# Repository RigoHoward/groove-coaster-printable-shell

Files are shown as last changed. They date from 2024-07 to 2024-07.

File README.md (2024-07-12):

<h1 align="center">Groove-Coaster Printable-Shell by Rigo Howard</h1>
<h3 align="center">A nice 3D printable frame/shell for a DIY Groove Coaster controller</h3>

<h3 align="left">Overview:</h3>
<p align="left">
Here you will find the needed 3D print files and directions to build a nice looking Groove Coaster shell and get your own DIY-ASC controller!</p>
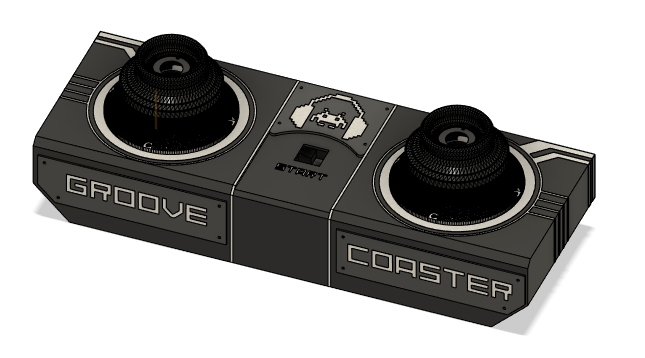
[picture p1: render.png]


<h3 align="left">Finished Controller Sample:</h3>
<p align="left">
Some glamour shots</p>
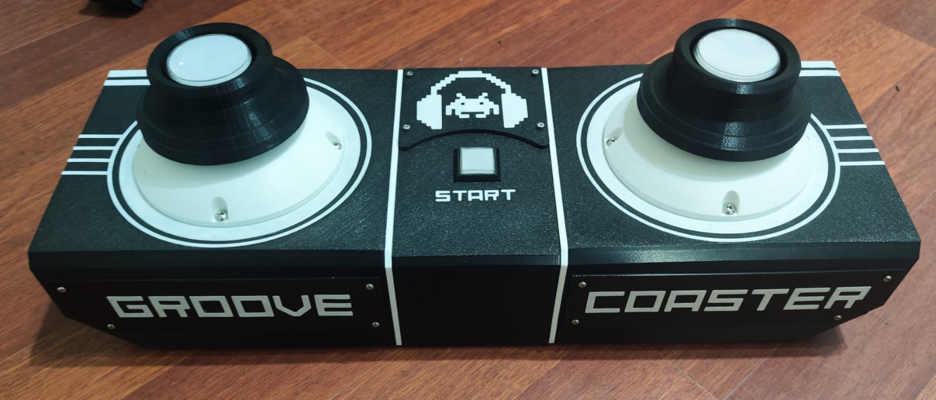
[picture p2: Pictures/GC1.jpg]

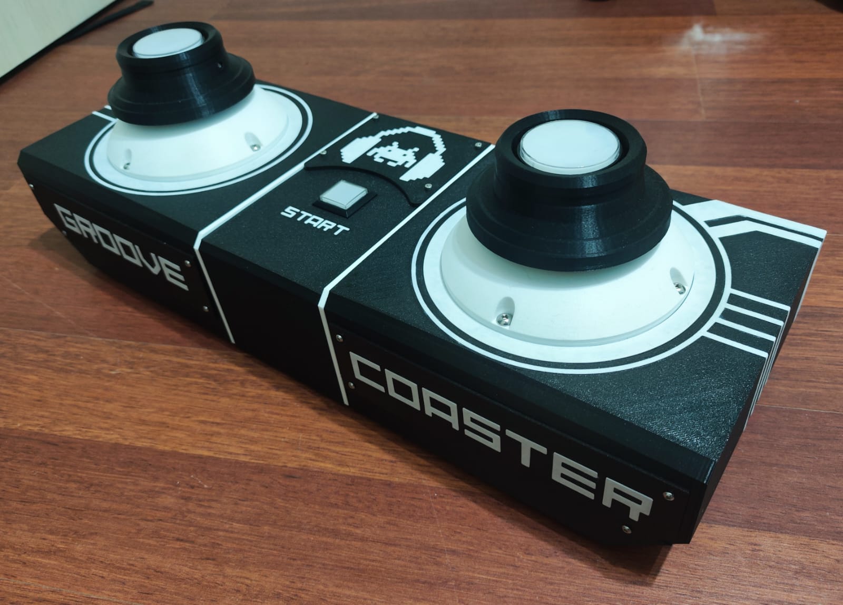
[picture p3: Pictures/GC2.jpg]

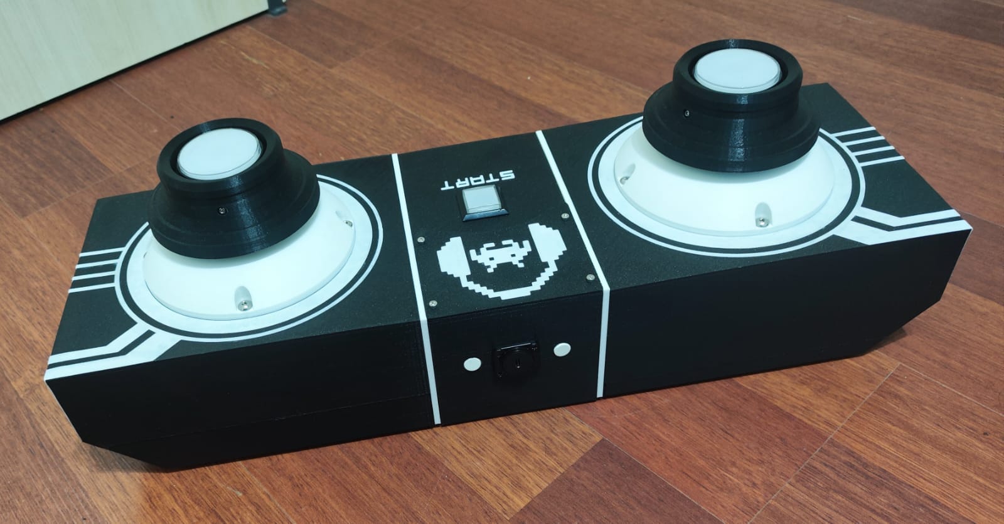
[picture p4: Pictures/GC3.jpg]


<h3 align="left">Extra parts/tools needed:</h3>
<p align="left">
Apart from the 3D printed parts you will need the following tools and materials (there are some Aliexpress links as reference):
  <ul>
  <li>1x Arduino Leonardo or clone board.</li>
  <li><a href="https://www.aliexpress.com/item/1005006560397920.html?spm=a2g0o.cart.0.0.67ac38daT6iGZ6&mp=1">2x Arcade sticks (Sanwa JLF like clones are good, there are 5 pin header and microswitch versions)</a></li>
  <li><a href="https://www.aliexpress.com/item/4000959586079.html?spm=a2g0o.cart.0.0.67ac38daT6iGZ6&mp=1">2x Round 60mm white pushbuttons.</a></li>
  <li><a href="https://www.aliexpress.com/item/33057798976.html?spm=a2g0o.cart.0.0.67ac38daT6iGZ6&mp=1">1x 33x33mm square white pushbutton.</a></li>
  <li>Some female quick disconnects to easily connect/disconnect wires to the sticks and pushbuttons.</li>
  <li><a href="https://www.aliexpress.com/item/1005002669156285.html?spm=a2g0o.cart.0.0.46e638da38WDFw&mp=1">2x Small round white momentary pushbuttons.</a></li>
  <li><a href="https://www.aliexpress.com/item/1005003082350902.html?spm=a2g0o.cart.0.0.67ac38daT6iGZ6&mp=1">2x Soft microswitches for the Left and Right pushbuttons.</a></li>    
  <li><a href="https://www.aliexpress.com/item/1005003307588072.html?spm=a2g0o.cart.0.0.389a38daMdQKNv&mp=1">1x Neutrik like female USB C to Female USB A panel connector.</a></li>
  <li>A few M5 bolts and nuts.</li>
  <li>A few M3 bolts.</li>  
  <li>Some M3 heat inserts.</li>
  <li>4x Rubber feet.</li>
  <li>1 meter of WS2812 ledstrip.</li>
  <li>1x short USB micro to USB-A wire to connect Arduino Leonardo to the USB-C panel connector.</li>
  <li>Solder, Flux and Soldering Iron (and basic soldering skills)</li>
  <li>Some wire cutter and a crimping tool for the quick disconnects.</li>      
  <li>Some shrink tube for cable joints.</li>  
  <li>About 3 meters of 24awg cable.</li>
  <li>Male dupont cables.</li>  
  <li>2x 5mm leds (colors of your preference)</li>  
  </ul>
</p>

<h3 align="left">Parts to print:</h3>
<p align="left">
  <ul>
  <li>1x Left, Center and Right frame.</li>
  <li>1x Bottom Left, Center and Right plate (you could use an accent color for this)</li>
  <li>2x Frame Spacer (you should use an accent color for this)</li>
  <li>1x Left, Right, Logo and Front plates.</li>  
  <li>1x each file on INSERTS folder (you should use an accent color for this)</li>
  <li>2x Joy Base, Joy Tube, Joy Button and Stick Spacer parts.</li>
  </ul>
</p>

<h3 align="left">Printing settings:</h3>
<p align="left">I used the following parameters on my slicer profile:
 <ul>
   <li>Layer Height 0.2 (i use a 0.4mm nozzle)</li>
   <li>3 or 4 walls/perimeters.</li>
   <li>15-20% infill is enough.</li>
   <li>Enabled normal supports on build plate only for Joy Tube and Joy Button parts.</li>
   <li>You really should use a brim or mouse ear brim for the Frame Parts (because they are big and take a long time to print)</li>
 </ul>  
</p>

<h3 align="left">Printing orientation:</h3>
<p align="left">All the Plate parts having some logo/letters engraved on them, must face up its engraving marks.
  For the rest, Please check the <a href="https://github.com/RigoHoward/groove-coaster-printable-shell/tree/main/Print_Orientation">Print_Orientarion</a> folder for pictured details.
</p>

<h3 align="left">Assembly:</h3>
<p align="left">
    <ul>
    <li>Attach the Insert parts to the Left, Center, Right Frame, the Logo Plate, Front Left and Right plates using some CA glue or whatever you use to glue your 3D printed parts.</li>      
    <li>Attach the USB-C panel to the back of the Center Frame and attach it using some M3 screws nuts and bolts. Also screw in the two small round white momentary pushbuttons and fix them with its own washer and nuts.</li>   
    <li>Using 4 M5 screws, washer and nuts put together the Left, Center and Right Frame parts using the 3D printed Frame Spacers between them to build the body of the controller.</li> 
    <li>Put 4 heated M3 inserts on the tiny holes on the top of the Center Frame to screw in the Logo plate later.</li>     
    <li>Using 4 M3 screws attach the Logo plate on top of the center Frame. Also with some M3 screws, washers and nuts fix the Front Left and Right Plate to the front of the Left and Right Frame parts.</li>      
    <li>Attach every JLF like joystick to the Stick Spacer part using two M5 screws on each Spacer.</li>    
    <li>Solder the corrresponding 3 wires (DIN, GND and VIN) to each piece of the ledstrip, then remove the back layer of the ledstrip to expose the sticky surface, and then pass the cables trough the hole in the inner wall of the Joy Base part and slide your ledstrip to glue it in place (leds should be facing outwards) repeat for the other Joy Base part.</li> 
    <li>Assemble the printed Joy Tube parts on the JLF like arcade sticks shafts using two M4 button head screws (do not overtight the screws)</li>  
    <li>Using 4 M5 screws, washer and nuts put together the Joy Base over the Left and Right Frame parts using the corresponding guide holes.</li>
    <li>Change the default microswitch on the 60mm buttons if you got the lighter ones before the next step.</li>      
    <li>Assemble the 60mm buttons on the Joy Button part, and solder the wires to the microswitch and leds.</li>
    <li>Assemble the Joy Button and the Joy Tube parts together routing the cables and twisting the recessed part into its lock position and then add a M3 screw to avoid unlocking.</li>
    <li>Solder each wire to the microswitchs or th 5 pin header (depending on what version you got) on each JLF like joystick.</li>
    <li>Solder the Center frame back momentary pushbuttons and the PLUS button LED to the corresponding pins in the Arduino Board (check the pinout section below)</li>
    <li>Put the heated M3 inserts on all the holes for the supporting Plate tabs for every Frame part at the bottom.</li>      
    <li>Assemble the Bottom Plates of each part of the frame using M3 screws and for each of the outer most sides use some rubber feet, confirm everything works before tightening up.</li>
  </ul>

</p>

<h3 align="left">Soldering:</h3>
<p align="left">
  <ul>
    <li>Solder a daisy chained GND wire to all leds, joysticks, buttons and ledstrips.</li>
    <li>Solder pins 4, 5, 6, 7, 8, 9, 10 and 11 to the left and right joysticks.</li>
    <li>Solder pins 0 and 1 to Left and Right buttons.</li>
    <li>Solder pins A0, A1 and 13 to the Minus, Home and Plus buttons.</li>
    <li>Solder pins 2, 3 and 12 to the Left, Right and Plus led buttons.</li>
    <li>Solder a daisy chained VCC wire to the VIN point on each piece of the ledstrip.</li>
    <li>Solder pins A2 and A3 to the DIN point on the Left and Right ledstrip piece.</li>
  </ul>
</p>

<h3 align="left">Flashing the Code:</h3>
<p align="left">
Follow the building instructions for the awesome <a href="https://github.com/CrazyRedMachine/LUFAHybridFightstick?tab=readme-ov-file#building-instructions">LUFAHybridFightstick</a> repository made by <b>CrazyRedMachine</b> until the fifth step and then flash the code i leave <a href="https://github.com/RigoHoward/groove-coaster-printable-shell/tree/main/Software/GC_RH">HERE</a> (which its actually his code with a different pinout and a rainbow animation effect for the ledstrip only)
</p>

<h3 align="left">Current Pinout:</h3>
<p align="left">
Here it is the pinout i used for each stick, button, led and ledstrip.
</p>

```
/* PINOUT (follows Nintendo naming (X=up, B=down)) */
#define PIN_UP    4
#define PIN_DOWN  5
#define PIN_LEFT  6
#define PIN_RIGHT 7
#define PIN_A     11          //XBOX B
#define PIN_B     9           //XBOX A  
#define PIN_X     8           //XBOX Y
#define PIN_Y     10          //XBOX X     
#define PIN_L     0           //XBOX LB
#define PIN_R     1           //XBOX RB
#define PIN_PLUS  13          //XBOX START
#define PIN_MINUS A0          //XBOX BACK
#define PIN_HOME  A1
#define PIN_L_LED  2
#define PIN_R_LED  3
#define PIN_PLUS_LED 12
#define DATA_PIN1 A2         //ledstrip Left
#define DATA_PIN2 A3         //ledstrip Right
```

<h3 align="left">Thanks to:</h3>
<p align="left">All the work done here was possible with the help of these awesome fellows:
<ul>
  <li><a href="https://github.com/CrazyRedMachine">CrazyRedMachine</a>: for the LufaHybridStick code and constant help on coding.</li>
  <li><a href="https://github.com/paatchii">Patchii</a>: for the initial STL files i used as reference to work on my remixed parts.</li>
  <li>Thomas (from C&S discord): for his modular 3D cases for rythm controllers inspiration.</li>
  <li>All the Cons & Stuff discord community for being so cool and nice.</li>
</ul>
</p>

<h3 align="left">Do you think i do cool stuff?, what about a nice cup of coffee for me?!:</h3>
<p><a href="https://www.buymeacoffee.com/rigohoward"> rigohoward</a></p><br><br>

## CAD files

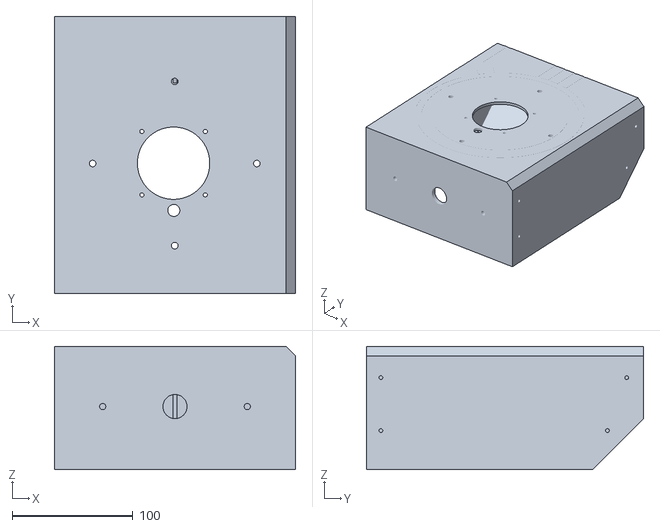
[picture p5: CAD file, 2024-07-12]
STLS/FRAME/Right_Frame.stl
200.0 x 230.0 x 102.4

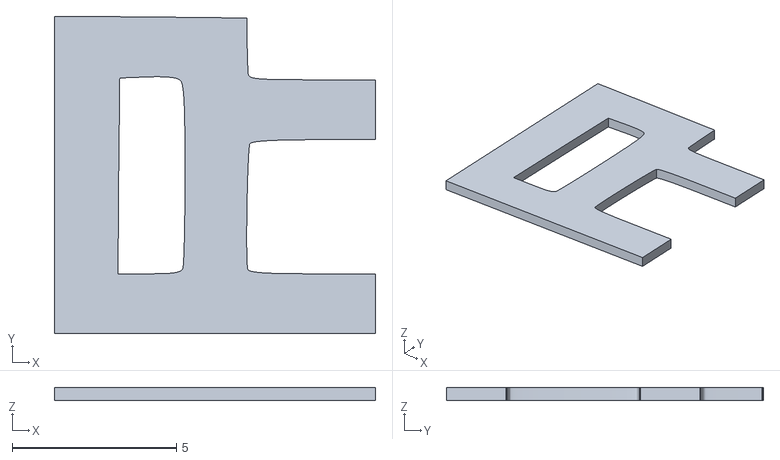
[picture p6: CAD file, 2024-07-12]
STLS/INSERTS/Center_Frame/START/R_start.stl
9.79 x 9.68 x 0.4

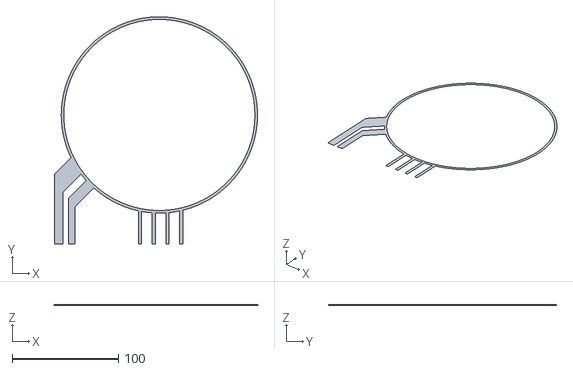
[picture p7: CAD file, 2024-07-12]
STLS/INSERTS/Left_Frame/Left_Frame_Insert_1.stl
191.3 x 214.3 x 0.4

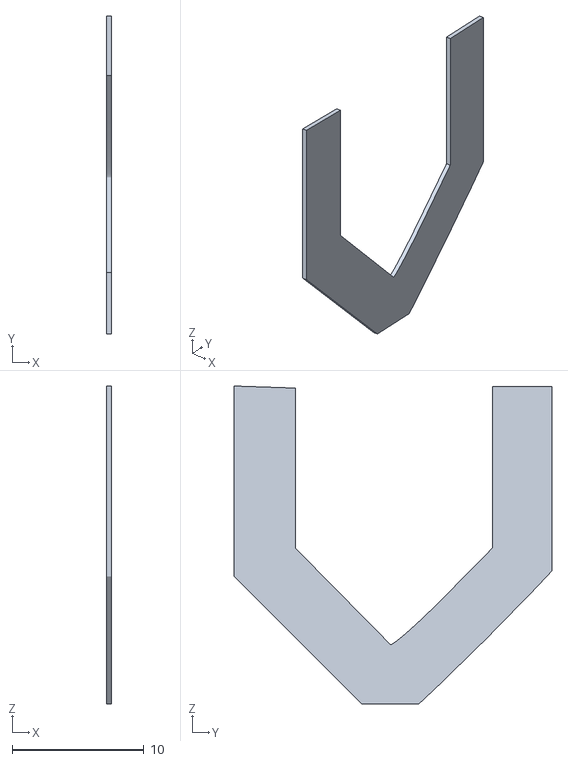
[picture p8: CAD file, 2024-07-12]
STLS/INSERTS/Left_Front_Plate/GROOVE/V_groove.stl
0.4 x 24.1 x 24.1

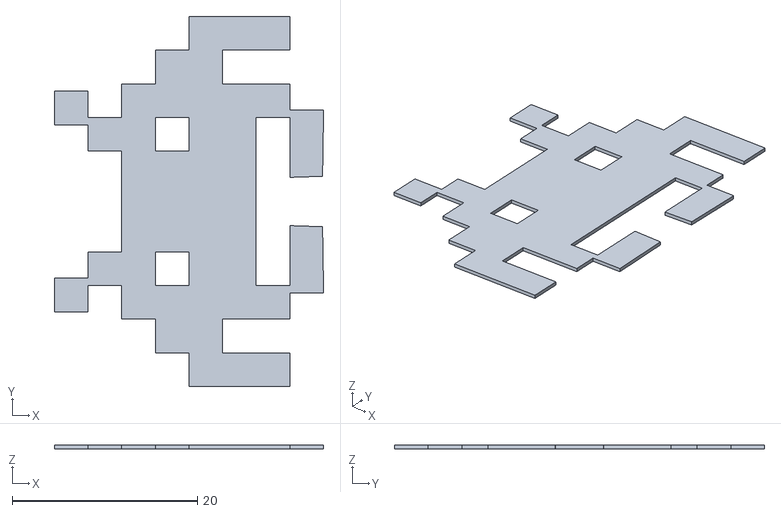
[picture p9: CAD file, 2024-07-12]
STLS/INSERTS/Logo_Plate/Invader.stl
29.1 x 39.9 x 0.4

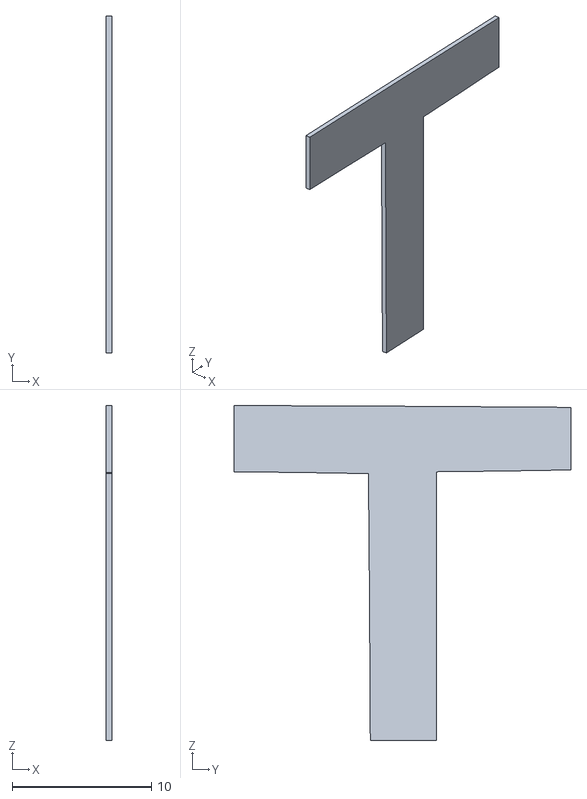
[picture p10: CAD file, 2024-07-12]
STLS/INSERTS/Right_Front_Plate/COASTER/T_coaster.stl
0.4 x 24.2 x 24.1

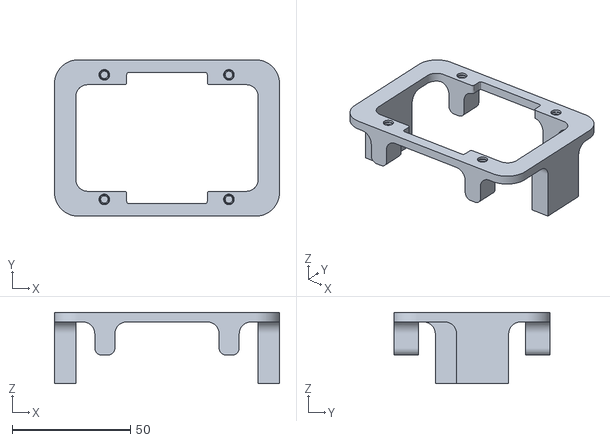
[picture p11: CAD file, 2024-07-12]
STLS/JOYSTICK/Stick_Spacer_JLF.stl
95.0 x 66.0 x 30.0

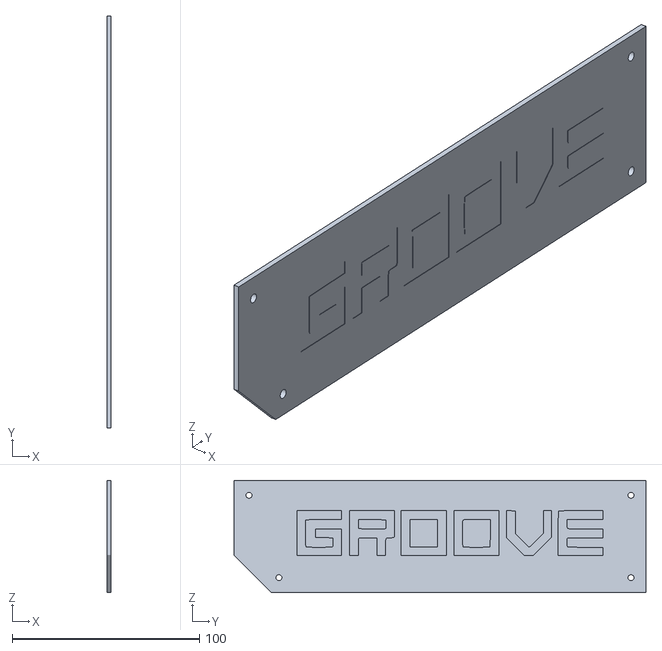
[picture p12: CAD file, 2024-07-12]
STLS/PLATES/Left_Front_Plate.stl
2.00 x 220.0 x 60.0

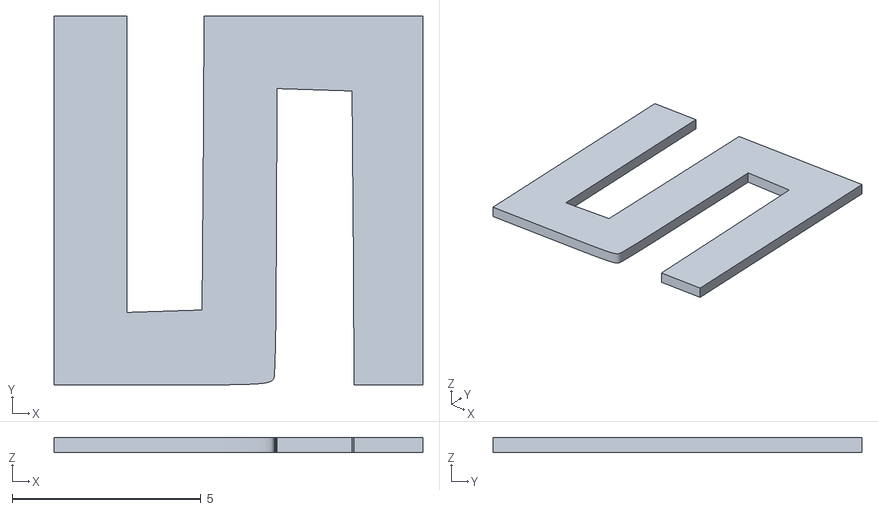
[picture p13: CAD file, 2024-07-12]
STLS/INSERTS/Center_Frame/START/S_start.stl
9.79 x 9.79 x 0.4

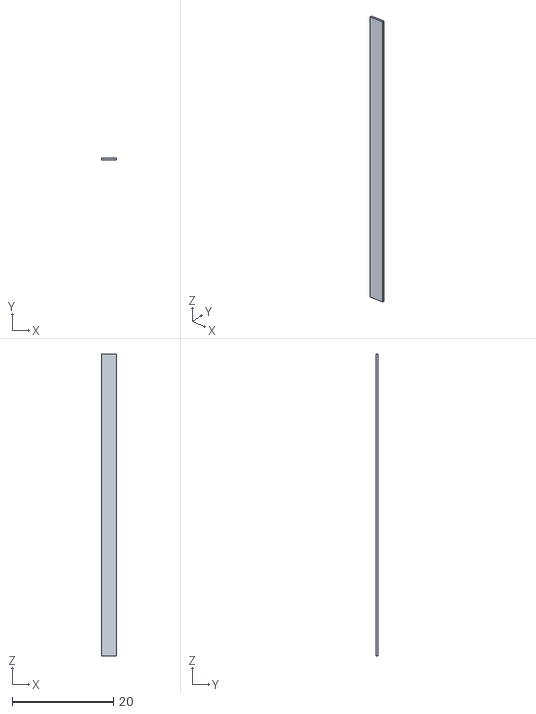
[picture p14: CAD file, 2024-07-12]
STLS/INSERTS/Left_Frame/Lx4.stl
3.00 x 0.4 x 59.8

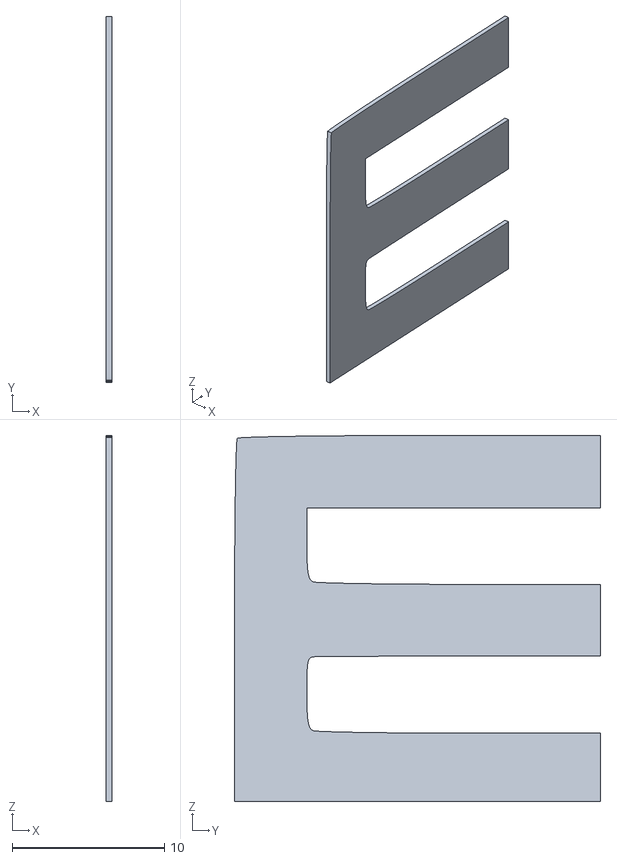
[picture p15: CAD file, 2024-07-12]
STLS/INSERTS/Left_Front_Plate/GROOVE/E_groove.stl
0.4 x 24.1 x 24.1

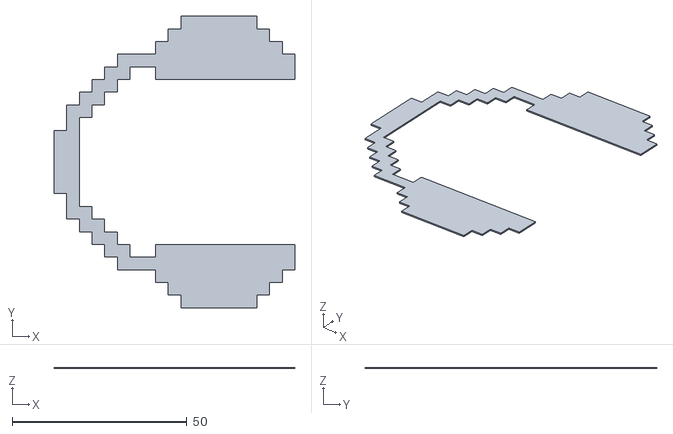
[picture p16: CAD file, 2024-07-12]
STLS/INSERTS/Logo_Plate/Headphones.stl
69.0 x 83.5 x 0.4

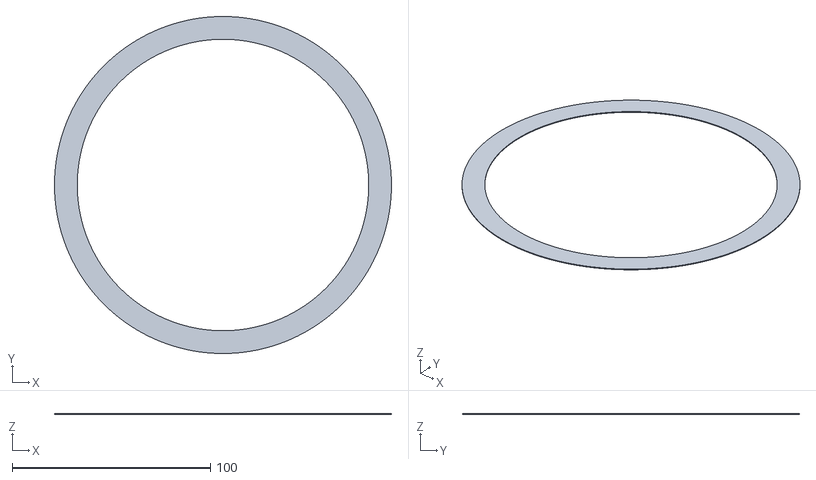
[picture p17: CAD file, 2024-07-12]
STLS/INSERTS/Right_Frame/Right_Frame_Insert_1.stl
170.0 x 170.0 x 0.4

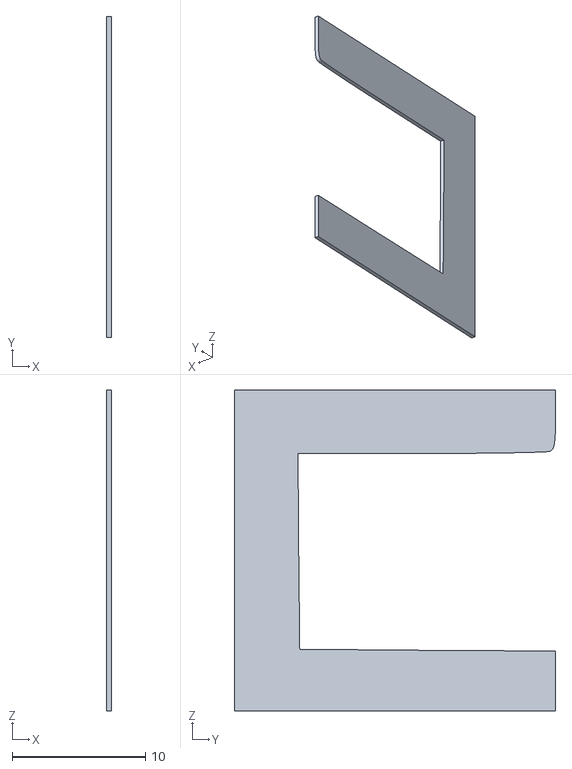
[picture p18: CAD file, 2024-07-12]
STLS/INSERTS/Right_Front_Plate/COASTER/C_coaster.stl
0.4 x 24.1 x 24.1

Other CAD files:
STLS/INSERTS/Right_Frame/Right_Frame_Insert_2.stl
STLS/FRAME/Left_Frame.stl
STLS/JOYSTICK/Joy_Base_x2.stl
STLS/PLATES/Center_Bottom_Plate.stl
STLS/FRAME/Center_Frame.stl
STLS/FRAME/Frame_spacer_x2.stl
STLS/INSERTS/Center_Frame/START/A_start.stl
STLS/INSERTS/Center_Frame/START/T1_start.stl
STLS/INSERTS/Center_Frame/START/T2_start.stl
STLS/INSERTS/Left_Frame/L_1.stl
STLS/INSERTS/Left_Frame/L_2.stl
STLS/INSERTS/Left_Frame/Left_Frame_Insert_2.stl
STLS/INSERTS/Left_Front_Plate/GROOVE/G_groove.stl
STLS/INSERTS/Left_Front_Plate/GROOVE/O1_groove.stl
STLS/INSERTS/Left_Front_Plate/GROOVE/O2_groove.stl
STLS/INSERTS/Left_Front_Plate/GROOVE/R_groove.stl
STLS/INSERTS/Right_Frame/R_1.stl
STLS/INSERTS/Right_Frame/R_2.stl
STLS/INSERTS/Right_Front_Plate/COASTER/A_coaster.stl
STLS/INSERTS/Right_Front_Plate/COASTER/E_coaster.stl
STLS/INSERTS/Right_Front_Plate/COASTER/O_coaster.stl
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

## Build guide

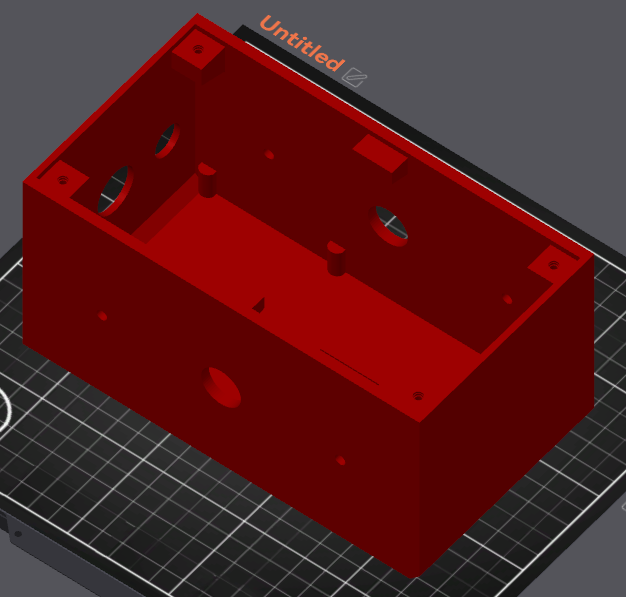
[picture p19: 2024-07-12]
Print_Orientation/Center_Frame.png

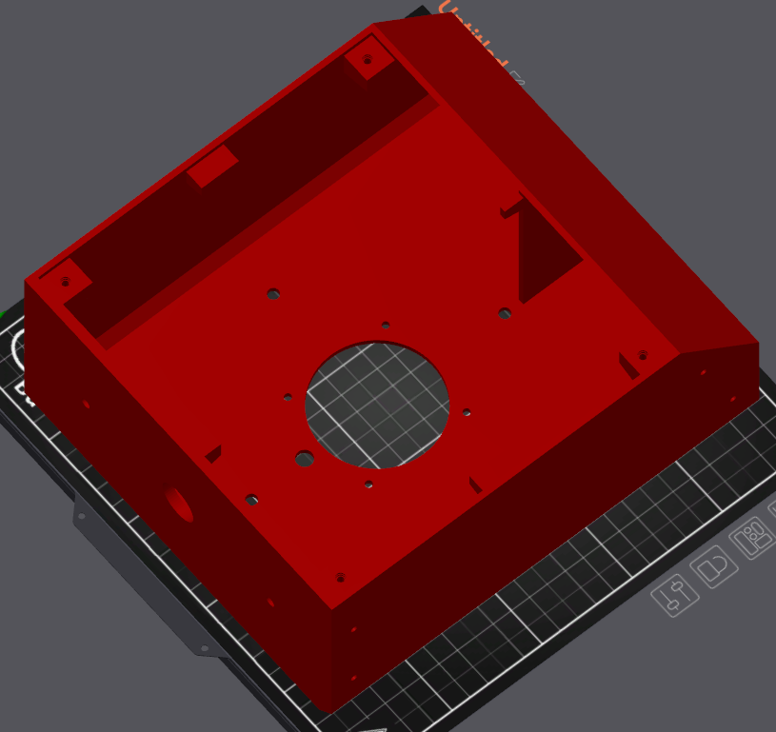
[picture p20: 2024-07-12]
Print_Orientation/Left&Right_Frame.png

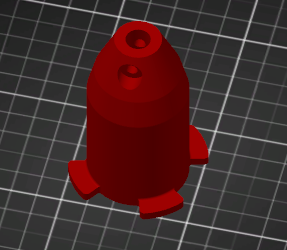
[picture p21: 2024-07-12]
Print_Orientation/Joy_Tube.png

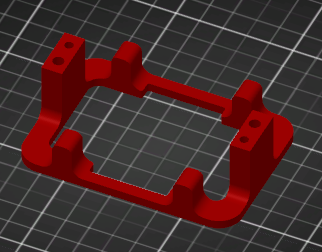
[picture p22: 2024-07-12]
Print_Orientation/Stick_Spacer.png

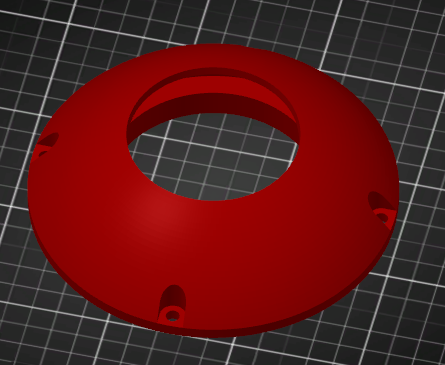
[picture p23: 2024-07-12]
Print_Orientation/Joy_Base.png

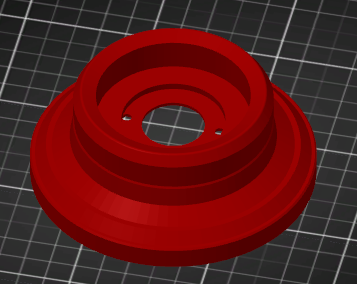
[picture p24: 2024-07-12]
Print_Orientation/Joy_Button.png

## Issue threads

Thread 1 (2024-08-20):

cannot get WS2812 ledstrip to light up

k1darklord, 2024-08-20:
Firstly thank you for your design it is fantastic!
I am however having a problem in getting the WS2812 ledstrip to light, I have wired it up to the 5v, gnd and pins a2 and a3 separate data but daisy chained power and ground.

Am I doing something wrong, won't lie I am not very familiar with using an Arduino leonardo so its all very new to me if you could provide any help and if I have posted this in the wrong area sorry.

Thanks for any help you may be able to provide.

RigoHoward, 2024-08-20:
Hey there, so youre building your own GC con nice!

Are you using an arduino leonardo board right?
If so, the pins for the ledstrips are digital pin 2 (D2/PD1) and 3 (D3/PD0):

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

 The analog pins A2 (PF5) and A3 (PF4) were not used originally.

Here is the complete pinout i used for my con:

´´´/* PINOUT (follows Nintendo naming (X=up, B=down)) */
#define PIN_UP    4
#define PIN_DOWN  5
#define PIN_LEFT  6
#define PIN_RIGHT 7
#define PIN_A     11          //XBOX B
#define PIN_B     9           //XBOX A
#define PIN_X     8           //XBOX Y
#define PIN_Y     10          //XBOX X
#define PIN_L     0           //XBOX LB
#define PIN_R     1           //XBOX RB
// Not used
//#define PIN_ZL    -         //XBOX LT
//#define PIN_ZR    -         //XBOX RT
//#define PIN_LS    -         //XBOX LS (left analog click)
//#define PIN_RS    -         //XBOX RS (right analog click)
#define PIN_PLUS  13          //XBOX START
#define PIN_MINUS A0          //XBOX BACK
#define PIN_HOME  A1
#define PIN_L_LED  2
#define PIN_R_LED  3
#define PIN_PLUS_LED 12´´´

(if you still want to use A2 and A3 pins, you could change the pins assignation for PIN_L_LED and PIN_R_LED before flashing the code to your board):
´´´
#define PIN_L_LED  A2
#define PIN_R_LED  A3
´´´

k1darklord, 2024-08-20:
Thank you so much for replying to me, I am building the controller and it looks amazing (all my 3d prints are done so its onto the wiring). I tried plugging the Arduino uno into my pc with the
5v going to pin +5v
ground going to the GND below +5v
data going to pin D2
They where the only pins populated on the board to test. The Pc sees it as a switch controller (pokken)
and still no lighting. They are 5v WS2812. Are the lights meant to come on when the arduino is plugged into a computer (or switch) or do they come on with a button press? I have no idea why these wont work and thank you for your assistance.

k1darklord, 2024-08-22:
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
I finished it, I still cannot get the led strips to light (the start button works how it should and lights when pressed).

I did have one problem the inputs where being dropped on quick button presses so I looked into the code and changed this:

#define MILLIDEBOUNCE 0 //Debounce time in milliseconds changed from 1 to 0

Now its really responsive just need to tinker with the fastled code to see if I can make it shine!

RigoHoward, 2024-08-22:
Oh its looking fantastic!, well done!

About the led strips, the lights are reactive only (they should light up when you move any of the sticks or press a button)

BTW do you have another Leonardo board to test a little script for the leds? (i experienced issues using with cheap aliexpress led strips in the past, so since then i always test them before using it on any of my diy projects)

I'm not an experienced GC player myself, but i didnt notice any dropped input but if i get better maybe i could start to notice it.

k1darklord, 2024-08-22:
Thanks, I'm really pleased with how it has come out and for a 3d print it feels substantial and not like its about to break! Fantastic design on your part and thank you again for sharing.

I checked for dropped inputs using a Joypad test program and for me there was dropped inputs until I changed that debounce setting, it could well be caused by the microswitches I am using but its sorted spot on now no delay or dropped inputs!

I have tried the LED strip on another Arduino using FastLED example code that animated them no problem. I was playing around with the code as I realised if I mess it up then I can always just put it back to stock really easily and not hurt anything so my plan is to have the lights animated in a circular motion from it being plugged in.

I have a few hours today so time to dip my toe back into coding which I have always found so difficult to understand but if I take my time I may get somewhere. Should I succeed I shall post back to let you know.

I did manage to make it so the start button is illuminated until it is pushed I wonder if it would be possible to make it pulse on and off???

RigoHoward, 2024-08-22:
Okay i check my wiring and this is how should ypu go using my code

Digital pins 2 & 3: for the led on the left and right top buttons on top of the sticks.
Digital pin 12: for the led on the start button on top.
Analog pins A2 & A3: are for the left and right led strips DIN point (both led strips should have 8 single leds on it)

So thats its how it goes (sorry for my earlier comment with a wrong pinout indication)

k1darklord, 2024-08-22:
Success! After literal hours of playing around and having close to zero idea what I was doing I managed to junk together working code, I have 16LEDs on each strip (set to low brightness so just in the limit for the Leonardo) and I have managed to get the lights animated spinning and looking all pretty! I could not figure out how to get the start button to pulse which would have been nice but I'm thrilled at where it is from having no lights to really nice lighting.

Here is the code if you want to have a look for yourself at any point and thank you again for such a good project! -

`/* Groove Coaster Controller Code for Arduino Leonardo and clones
 * 2 Joystick + 5 Buttons + 2 reactive LEDs + 2 reactive Ledstrips
 *  The original code was made by CrazyRedMachine https://github.com/CrazyRedMachine/LUFAHybridFightstick
 *  dont forget to visit his amazing Github page!
 *  Modifications made for my own personal use and this awesome controller i made :)
 * Edited again by an idjoit! to make the LEDS animated
*/
#include "LUFAConfig.h"
#include <LUFA.h>
#include "XS_HID.h"
#define BOUNCE_WITH_PROMPT_DETECTION
#include <Bounce2.h>
#include <EEPROM.h>
#include <inttypes.h>
#include <FastLED.h>

/* in case you want to disable one type of gamepad */
//#define DISABLE_XINPUT
#define DISABLE_NSWITCH

//use real analog sticks
//#define WITH_ANALOG
#define DEADZONE     50

// Enable on-the-fly SOCD config. If disabled, it'll lock in
// the default configuration but still use the SOCD resolution code.
// #define ENABLE_SOCD_CONFIG

//make it so holding start+select triggers the HOME button
//#define HOME_HOTKEY
//delay in ms for start+select to become HOME in HOME_HOTKEY mode
#define HOME_DELAY 1000

/* PINOUT (follows Nintendo naming (X=up, B=down)) */
#define PIN_UP    4
#define PIN_DOWN  5
#define PIN_LEFT  6
#define PIN_RIGHT 7
#define PIN_A     11          //XBOX B
#define PIN_B     9           //XBOX A
#define PIN_X     8           //XBOX Y
#define PIN_Y     10          //XBOX X
#define PIN_L     0           //XBOX LB
#define PIN_R     1           //XBOX RB
// Not used
//#define PIN_ZL    -         //XBOX LT
//#define PIN_ZR    -         //XBOX RT
//#define PIN_LS    -         //XBOX LS (left analog click)
//#define PIN_RS    -         //XBOX RS (right analog click)
#define PIN_PLUS  13          //XBOX START
#define PIN_MINUS A0          //XBOX BACK
#define PIN_HOME  A1
#define PIN_L_LED  2
#define PIN_R_LED  3
#define PIN_PLUS_LED 12

#ifdef WITH_ANALOG
#define PIN_LANALOGX    MOSI
#define PIN_LANALOGY    MISO
#define PIN_RANALOGX    MOSI
#define PIN_RANALOGY    MISO

typedef struct point_s {
  int x;
  int y;
} point_t;

typedef struct range_s {
  point_t min;
  point_t max;
  point_t center;
} range_t;

range_t g_range_l = {{400, 400}, {600, 600}, {511, 511}};
range_t g_range_r = {{400, 400}, {600, 600}, {511, 511}};

bool g_calibrating = false;
#endif

/* Buttons declarations */
#define MILLIDEBOUNCE 0 //Debounce time in milliseconds
unsigned long startAndSelTime = 0;
unsigned long currTime = 0;

byte internalButtonStatus[4];

Bounce joystickUP = Bounce();
Bounce joystickDOWN = Bounce();
Bounce joystickLEFT = Bounce();
Bounce joystickRIGHT = Bounce();
Bounce buttonA = Bounce();
Bounce buttonB = Bounce();
Bounce buttonX = Bounce();
Bounce buttonY = Bounce();
Bounce buttonL = Bounce();
Bounce buttonR = Bounce();
// Not used
//Bounce buttonZL = Bounce();
//Bounce buttonZR = Bounce();
//Bounce buttonLS = Bounce();
//Bounce buttonRS = Bounce();
Bounce buttonPLUS = Bounce();
Bounce buttonMINUS = Bounce();
Bounce buttonHOME = Bounce();

/* MODE DECLARATIONS */
typedef enum {
  RIGHT_ANALOG_MODE,
  ANALOG_MODE,
  DIGITAL,
} State_t;
State_t state;

typedef enum {
  NEUTRAL,    // LEFT/UP + DOWN/RIGHT = NEUTRAL
  NEGATIVE,   // LEFT/UP beats DOWN/RIGHT
  POSITIVE,   // DOWN/RIGHT beats LEFT/UP
  LAST_INPUT, //Last input has priority; not a valid state if being used for initial_input
} Socd_t;
Socd_t x_socd_type = NEUTRAL; // controls left/right and up/down resolution type
Socd_t y_socd_type = NEGATIVE;
Socd_t x_initial_input, y_initial_input = NEUTRAL;

/* mode selectors */
bool xinput;
bool modeChanged;

#define DATA_PIN1    A3
#define DATA_PIN2    A2
//#define CLK_PIN   4
#define LED_TYPE    WS2812
#define COLOR_ORDER GRB
#define NUM_LEDS    18
CRGB leds[NUM_LEDS];

#define BRIGHTNESS          20
#define FRAMES_PER_SECOND  60

void checkModeChange() {
  if (buttonStatus[BUTTONSTART] && buttonStatus[BUTTONSELECT])
  {
#ifdef ENABLE_SOCD_CONFIG
    if (buttonStatus[BUTTONL3] && buttonStatus[BUTTONR3])
    {
      if (!modeChanged)
      {
        // read inputs at time of press
        bool up = !joystickUP.read();
        bool down = !joystickDOWN.read();
        bool left = !joystickLEFT.read();
        bool right = !joystickRIGHT.read();

        if (up && down)
          y_socd_type = LAST_INPUT;
        else if (up)
          y_socd_type = NEGATIVE;
        else if (down)
          y_socd_type = POSITIVE;
        else if (!up && !down)
          y_socd_type = NEUTRAL;

        if (left && right)
          x_socd_type = LAST_INPUT;
        else if (left)
          x_socd_type = NEGATIVE;
        else if (right)
          x_socd_type = POSITIVE;
        else if (!left && !right)
          x_socd_type = NEUTRAL;

        EEPROM.put(4, x_socd_type);
        EEPROM.put(6, y_socd_type);
        modeChanged = true;
      }
    }
    else
#endif
    if ( !modeChanged )
    {
        bool need_update = true;
        if (internalButtonStatus[BUTTONLEFT])
          state = ANALOG_MODE;
        else if (internalButtonStatus[BUTTONRIGHT])
          state = RIGHT_ANALOG_MODE;
        else if (internalButtonStatus[BUTTONUP])
          state = DIGITAL;
        else need_update = false;

        if (need_update) EEPROM.put(0, state);
        modeChanged = true;
    }
    else
    {
      modeChanged = false;
    }
  }
}

void setupPins() {
  joystickUP.attach(PIN_UP, INPUT_PULLUP);
  joystickDOWN.attach(PIN_DOWN, INPUT_PULLUP);
  joystickLEFT.attach(PIN_LEFT, INPUT_PULLUP);
  joystickRIGHT.attach(PIN_RIGHT, INPUT_PULLUP);
  buttonA.attach(PIN_A, INPUT_PULLUP);    // XBOX B
  buttonB.attach(PIN_B, INPUT_PULLUP);    // XBOX A
  buttonX.attach(PIN_X, INPUT_PULLUP);    // XBOX Y
  buttonY.attach(PIN_Y, INPUT_PULLUP);    // XBOX X
  buttonL.attach(PIN_L, INPUT_PULLUP);    // XBOX LB
  buttonR.attach(PIN_R, INPUT_PULLUP);    // XBOX RB
  // Not used
  //buttonZL.attach(PIN_ZL, INPUT_PULLUP);     // XBOX LT
  //buttonZR.attach(PIN_ZR, INPUT_PULLUP);     // XBOX RT
  //buttonLS.attach(PIN_LS, INPUT_PULLUP);     // XBOX LS
  //buttonRS.attach(PIN_RS, INPUT_PULLUP);     // XBOX RS
  buttonPLUS.attach(PIN_PLUS, INPUT_PULLUP);   // XBOX START
  buttonMINUS.attach(PIN_MINUS, INPUT_PULLUP); // XBOX BACK
  buttonHOME.attach(PIN_HOME, INPUT_PULLUP);
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

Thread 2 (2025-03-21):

Spacer Hole Orientation

TriumphantBass, 2025-03-21:
Hi-
Struggling with
> Attach every JLF like joystick to the Stick Spacer part using two M5 screws on each Spacer.

I don't see any orientation where this spacer fits around the joystick, or where the screw holes make sense.

I am using https://focusattack.com/sanwa-jlf-tp-8yt-joystick-precursor-to-jlx-tp-8yt/

How is this part meant to be attached?

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

RigoHoward, 2025-03-25:
Hello!, you actually need to remove the metal plate on the arcade stick in order to attach the joystick spacer ;)

TriumphantBass, 2025-08-01:
Hi @RigoHoward , sorry for the long follow up, I finally started assembling and I missed the edit- I had taken off the plate to see what would fit, but I got stumped again trying to put them into place,

Like- ir looks like these four holes on the shaper mostly line up with those on the shell, so I can see sticking inserts in the spacer and screwing it to the top of the frame
but with that orientation, even if my stick didn't have the wrong plate shape I don't see a good way to get it to the bottom

I can probably mod the spacer file a bit myself, but it's a bit unclear how the spacer-frame-stick layout is supposed to connect and rest.

Do you maybe have a cutaway render if not constsruction photos?

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

TriumphantBass, 2025-08-02:
Also it looks like what I ended up getting were

`SEIMITSU LS-32-01-SC Joystick with SE plate`

TriumphantBass, 2025-08-06:
Disregard, buying a universal plate got me unstuck!

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

Closed 2025-08-06.

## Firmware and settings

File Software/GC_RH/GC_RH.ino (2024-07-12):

/* Groove Coaster Controller Code for Arduino Leonardo and clones
 * 2 Joystick + 5 Buttons + 2 reactive LEDs + 2 reactive Ledstrips
 *  The original code was made by CrazyRedMachine https://github.com/CrazyRedMachine/LUFAHybridFightstick
 *  dont forget to visit his amazing Github page!
 *  Modifications made for my own personal use and this awesome controller i made :)
*/
#include "LUFAConfig.h"
#include <LUFA.h>
#include "XS_HID.h"
#define BOUNCE_WITH_PROMPT_DETECTION
#include <Bounce2.h>
#include <EEPROM.h>
#include <inttypes.h>
#include <FastLED.h>

/* in case you want to disable one type of gamepad */
//#define DISABLE_NSWITCH
#define DISABLE_XINPUT

//use real analog sticks
//#define WITH_ANALOG
#define DEADZONE     50

// Enable on-the-fly SOCD config. If disabled, it'll lock in
// the default configuration but still use the SOCD resolution code.
// #define ENABLE_SOCD_CONFIG

//make it so holding start+select triggers the HOME button
//#define HOME_HOTKEY
//delay in ms for start+select to become HOME in HOME_HOTKEY mode
#define HOME_DELAY 1000

/* PINOUT (follows Nintendo naming (X=up, B=down)) */
#define PIN_UP    4
#define PIN_DOWN  5
#define PIN_LEFT  6
#define PIN_RIGHT 7
#define PIN_A     11          //XBOX B
#define PIN_B     9           //XBOX A  
#define PIN_X     8           //XBOX Y
#define PIN_Y     10          //XBOX X     
#define PIN_L     0           //XBOX LB
#define PIN_R     1           //XBOX RB
// Not used
//#define PIN_ZL    -         //XBOX LT
//#define PIN_ZR    -         //XBOX RT
//#define PIN_LS    -         //XBOX LS (left analog click)
//#define PIN_RS    -         //XBOX RS (right analog click)
#define PIN_PLUS  13          //XBOX START
#define PIN_MINUS A0          //XBOX BACK
#define PIN_HOME  A1
#define PIN_L_LED  2
#define PIN_R_LED  3
#define PIN_PLUS_LED 12

#ifdef WITH_ANALOG
#define PIN_LANALOGX    MOSI
#define PIN_LANALOGY    MISO
#define PIN_RANALOGX    MOSI
#define PIN_RANALOGY    MISO

typedef struct point_s {
  int x;
  int y;
} point_t;

typedef struct range_s {
  point_t min;
  point_t max;
  point_t center;
} range_t;

range_t g_range_l = {{400, 400}, {600, 600}, {511, 511}};
range_t g_range_r = {{400, 400}, {600, 600}, {511, 511}};

bool g_calibrating = false;
#endif

/* Buttons declarations */
#define MILLIDEBOUNCE 1 //Debounce time in milliseconds
unsigned long startAndSelTime = 0;
unsigned long currTime = 0;

byte internalButtonStatus[4];

Bounce joystickUP = Bounce();
Bounce joystickDOWN = Bounce();
Bounce joystickLEFT = Bounce();
Bounce joystickRIGHT = Bounce();
Bounce buttonA = Bounce();
Bounce buttonB = Bounce();
Bounce buttonX = Bounce();
Bounce buttonY = Bounce();
Bounce buttonL = Bounce();
Bounce buttonR = Bounce();
// Not used
//Bounce buttonZL = Bounce();
//Bounce buttonZR = Bounce();
//Bounce buttonLS = Bounce();
//Bounce buttonRS = Bounce();
Bounce buttonPLUS = Bounce();
Bounce buttonMINUS = Bounce();
Bounce buttonHOME = Bounce();

/* MODE DECLARATIONS */
typedef enum {
  RIGHT_ANALOG_MODE,
  ANALOG_MODE,
  DIGITAL,
} State_t;
State_t state;

typedef enum {
  NEUTRAL,    // LEFT/UP + DOWN/RIGHT = NEUTRAL
  NEGATIVE,   // LEFT/UP beats DOWN/RIGHT
  POSITIVE,   // DOWN/RIGHT beats LEFT/UP
  LAST_INPUT, //Last input has priority; not a valid state if being used for initial_input
} Socd_t;
Socd_t x_socd_type = NEUTRAL; // controls left/right and up/down resolution type
Socd_t y_socd_type = NEGATIVE;
Socd_t x_initial_input, y_initial_input = NEUTRAL;

/* mode selectors */
bool xinput;
bool modeChanged;

// Setup Fastled
#define DATA_PIN1 A2
#define DATA_PIN2 A3

// How many leds in your strip?
#define NUM_LEDS 8

// Define the array of leds
CRGB leds1[NUM_LEDS];
CRGB leds2[NUM_LEDS];

void checkModeChange() {
  if (buttonStatus[BUTTONSTART] && buttonStatus[BUTTONSELECT])
  {
#ifdef ENABLE_SOCD_CONFIG
    if (buttonStatus[BUTTONL3] && buttonStatus[BUTTONR3])
    {
      if (!modeChanged)
      {
        // read inputs at time of press
        bool up = !joystickUP.read();
        bool down = !joystickDOWN.read();
        bool left = !joystickLEFT.read();
        bool right = !joystickRIGHT.read();

        if (up && down)
          y_socd_type = LAST_INPUT;
        else if (up)
          y_socd_type = NEGATIVE;
        else if (down)
          y_socd_type = POSITIVE;
        else if (!up && !down)
          y_socd_type = NEUTRAL;

        if (left && right)
          x_socd_type = LAST_INPUT;
        else if (left)
          x_socd_type = NEGATIVE;
        else if (right)
          x_socd_type = POSITIVE;
        else if (!left && !right)
          x_socd_type = NEUTRAL;

        EEPROM.put(4, x_socd_type);
        EEPROM.put(6, y_socd_type);
        modeChanged = true;
      }
    }
    else 
#endif   
    if ( !modeChanged )
    {
        bool need_update = true;
        if (internalButtonStatus[BUTTONLEFT])
          state = ANALOG_MODE;
        else if (internalButtonStatus[BUTTONRIGHT])
          state = RIGHT_ANALOG_MODE;
        else if (internalButtonStatus[BUTTONUP])
          state = DIGITAL;
        else need_update = false;

        if (need_update) EEPROM.put(0, state);
        modeChanged = true;
    }
    else
    {
      modeChanged = false;
    }
  }
}

void setupPins() {
  joystickUP.attach(PIN_UP, INPUT_PULLUP);
  joystickDOWN.attach(PIN_DOWN, INPUT_PULLUP);
  joystickLEFT.attach(PIN_LEFT, INPUT_PULLUP);
  joystickRIGHT.attach(PIN_RIGHT, INPUT_PULLUP);
  buttonA.attach(PIN_A, INPUT_PULLUP);    // XBOX B
  buttonB.attach(PIN_B, INPUT_PULLUP);    // XBOX A
  buttonX.attach(PIN_X, INPUT_PULLUP);    // XBOX Y
  buttonY.attach(PIN_Y, INPUT_PULLUP);    // XBOX X
  buttonL.attach(PIN_L, INPUT_PULLUP);    // XBOX LB
  buttonR.attach(PIN_R, INPUT_PULLUP);    // XBOX RB
  // Not used
  //buttonZL.attach(PIN_ZL, INPUT_PULLUP);     // XBOX LT
  //buttonZR.attach(PIN_ZR, INPUT_PULLUP);     // XBOX RT
  //buttonLS.attach(PIN_LS, INPUT_PULLUP);     // XBOX LS
  //buttonRS.attach(PIN_RS, INPUT_PULLUP);     // XBOX RS
  buttonPLUS.attach(PIN_PLUS, INPUT_PULLUP);   // XBOX START
  buttonMINUS.attach(PIN_MINUS, INPUT_PULLUP); // XBOX BACK
  buttonHOME.attach(PIN_HOME, INPUT_PULLUP);

  joystickUP.interval(MILLIDEBOUNCE);
  joystickDOWN.interval(MILLIDEBOUNCE);
  joystickLEFT.interval(MILLIDEBOUNCE);
  joystickRIGHT.interval(MILLIDEBOUNCE);
  buttonA.interval(MILLIDEBOUNCE);
  buttonB.interval(MILLIDEBOUNCE);
  buttonX.interval(MILLIDEBOUNCE);
  buttonY.interval(MILLIDEBOUNCE);
  buttonL.interval(MILLIDEBOUNCE);
  buttonR.interval(MILLIDEBOUNCE);
  // Not used
  //buttonZL.interval(MILLIDEBOUNCE);
  //buttonZR.interval(MILLIDEBOUNCE);
  //buttonLS.interval(MILLIDEBOUNCE);
  //buttonRS.interval(MILLIDEBOUNCE);
  buttonPLUS.interval(MILLIDEBOUNCE);
  buttonMINUS.interval(MILLIDEBOUNCE);
  buttonHOME.interval(MILLIDEBOUNCE);

  pinMode(PIN_L_LED, OUTPUT);
  pinMode(PIN_R_LED, OUTPUT);
  pinMode(PIN_PLUS_LED, OUTPUT);
}

void setup() {

  modeChanged = false;
  EEPROM.get(0, state);
  EEPROM.get(2, xinput);
#ifdef ENABLE_SOCD_CONFIG
  EEPROM.get(4, x_socd_type);
  EEPROM.get(6, y_socd_type);
#endif
  setupPins();
  delay(500);
  FastLED.clear();  // Initialize all LEDs to "off"
  
#ifdef DISABLE_NSWITCH
#warning "NSWITCH mode is disabled, will act only as an XInput controller"
  /* force Xinput */
  xinput = true;
#else
#ifdef DISABLE_XINPUT
#warning "XINPUT mode is disabled, will act only as a Nintendo switch controller"
  /* force nswitch */
  xinput = false;
#else
  /* set xinput mode according to held button */
  // if select is held on boot, NSWitch mode
  int value = digitalRead(PIN_MINUS);
  if (value == LOW)
  {
    xinput = false;
    EEPROM.put(2, xinput);
  }
  // if start is held on boot, XInput mode
  else {
    value = digitalRead(PIN_PLUS);
    if (value == LOW)
    {
      xinput = true;
      EEPROM.put(2, xinput);
    }
  }
#endif
#endif

#ifdef WITH_ANALOG
//  if (digitalRead(PIN_LS) == LOW) && digitalRead(PIN_RS) == LOW)
//  {
//    g_calibrating = true;
//  }

  g_range_l.center.x = analogRead(PIN_LANALOGX);
  g_range_l.center.y = analogRead(PIN_LANALOGY);
  g_range_r.center.x = analogRead(PIN_RANALOGX);
  g_range_r.center.y = analogRead(PIN_RANALOGY);

  if (!g_calibrating)
  {
    EEPROM.get(8, g_range_l.min.x);
    EEPROM.get(10, g_range_l.min.y);
    EEPROM.get(12, g_range_l.max.x);
    EEPROM.get(14, g_range_l.max.y);

    EEPROM.get(16, g_range_r.min.x);
    EEPROM.get(18, g_range_r.min.y);
    EEPROM.get(20, g_range_r.max.x);
    EEPROM.get(22, g_range_r.max.y);
  }
#endif

  SetupHardware(xinput);
  GlobalInterruptEnable();

 // ## Clockless types ##
  FastLED.addLeds<WS2811, DATA_PIN1, GRB>(leds1, NUM_LEDS);  // GRB ordering is typical  
  FastLED.addLeds<WS2811, DATA_PIN2, GRB>(leds2, NUM_LEDS);  // GRB ordering is typical
}


void loop() {
  currTime = millis();
#ifdef WITH_ANALOG
  axisRead();
#endif
  buttonRead();
  checkModeChange();
  convert_dpad();
  send_pad_state();
  FastLED.show();
}

#ifdef WITH_ANALOG
void axisRead()
{
  point_t curr;

  // left analog X
  curr.x = analogRead(PIN_LANALOGX);
  curr.y = analogRead(PIN_LANALOGY);

  if ((curr.x - g_range_l.center.x < DEADZONE) && (curr.x - g_range_l.center.x > -DEADZONE))
    buttonStatus[AXISLX] = 127;
  else if (curr.x < g_range_l.min.x) {
    g_range_l.min.x = curr.x - 10;

    if (g_calibrating)
      EEPROM.put(8, g_range_l.min.x);

    buttonStatus[AXISLX] = 0;
  }
  else if (curr.x > g_range_l.max.x) {
    g_range_l.max.x = curr.x + 10;
    if (g_calibrating)
      EEPROM.put(12, g_range_l.max.x);
    buttonStatus[AXISLX] = 255;
  } else if (curr.x > g_range_l.center.x) {
    buttonStatus[AXISLX] = map(curr.x, g_range_l.center.x, g_range_l.max.x, 127, 255);
  } else if (curr.x < g_range_l.center.x) {
    buttonStatus[AXISLX] = map(curr.x, g_range_l.min.x, g_range_l.center.x, 0, 127);
  }
  buttonStatus[AXISLX] *= -1;

  if ((curr.y - g_range_l.center.y < DEADZONE) && (curr.y - g_range_l.center.y > -DEADZONE))
    buttonStatus[AXISLY] = 127;
  else if (curr.y < g_range_l.min.y) {
    g_range_l.min.y = curr.y - 10;
    if (g_calibrating)
      EEPROM.put(10, g_range_l.min.y);
    buttonStatus[AXISLY] = 0;
  }
  else if (curr.y > g_range_l.max.y) {
    g_range_l.max.y = curr.y + 10;
    if (g_calibrating)
      EEPROM.put(14, g_range_l.max.y);
    buttonStatus[AXISLY] = 255;
  } else if (curr.y > g_range_l.center.y) {
    buttonStatus[AXISLY] = map(curr.y, g_range_l.center.y, g_range_l.max.y, 127, 255);
  } else if (curr.y < g_range_l.center.y) {
    buttonStatus[AXISLY] = map(curr.y, g_range_l.min.y, g_range_l.center.y, 0, 127);
  }
  buttonStatus[AXISLY] *= -1;


  // right analog

  curr.x = analogRead(PIN_RANALOGX);
  curr.y = analogRead(PIN_RANALOGY);

  if ((curr.x - g_range_r.center.x < 50) && (curr.x - g_range_r.center.x > -50))
    buttonStatus[AXISRX] = 127;
  else if (curr.x < g_range_r.min.x) {
    g_range_r.min.x = curr.x - 10;
    if (g_calibrating)
      EEPROM.put(16, g_range_r.min.x);
    buttonStatus[AXISRX] = 0;
  }
  else if (curr.x > g_range_r.max.x) {
    g_range_r.max.x = curr.x + 10;
    if (g_calibrating)
      EEPROM.put(20, g_range_r.max.x);
    buttonStatus[AXISRX] = 255;
  } else if (curr.x > g_range_r.center.x) {
    buttonStatus[AXISRX] = map(curr.x, g_range_r.center.x, g_range_r.max.x, 127, 255);
  } else if (curr.x < g_range_r.center.x) {
    buttonStatus[AXISRX] = map(curr.x, g_range_r.min.x, g_range_r.center.x, 0, 127);
  }
  buttonStatus[AXISRX] *= -1;


  if ((curr.y - g_range_r.center.y < 50) && (curr.y - g_range_r.center.y > -50))
    buttonStatus[AXISRY] = 127;
  else if (curr.y < g_range_r.min.y) {
    g_range_r.min.y = curr.y - 10;
    if (g_calibrating)
      EEPROM.put(18, g_range_r.min.y);
    buttonStatus[AXISRY] = 0;
  }
  else if (curr.y > g_range_r.max.y) {
    g_range_r.max.y = curr.y + 10;
    if (g_calibrating)
      EEPROM.put(22, g_range_r.max.y);
    buttonStatus[AXISRY] = 255;
  } else if (curr.y > g_range_r.center.y) {
    buttonStatus[AXISRY] = map(curr.y, g_range_r.center.y, g_range_r.max.y, 127, 255);
  } else if (curr.y < g_range_r.center.y) {
    buttonStatus[AXISRY] = map(curr.y, g_range_r.min.y, g_range_r.center.y, 0, 127);
  }
  buttonStatus[AXISRY] *= -1;

}
#endif

void convert_dpad() {
  byte cleanButtonStatus[4] = {0};
  // Prevent SOCD inputs (left+right or up+down) from making it to the logic below.
  clean_all_socd(internalButtonStatus, cleanButtonStatus, x_socd_type, y_socd_type);

#ifdef WITH_ANALOG
  // force digital mode for dpad (TODO: allow the other modes as well)
  buttonStatus[BUTTONUP] = cleanButtonStatus[BUTTONUP];
  buttonStatus[BUTTONDOWN] = cleanButtonStatus[BUTTONDOWN];
  buttonStatus[BUTTONLEFT] = cleanButtonStatus[BUTTONLEFT];
  buttonStatus[BUTTONRIGHT] = cleanButtonStatus[BUTTONRIGHT];
  return;
#endif

  switch (state)
  {
    case DIGITAL:
      buttonStatus[AXISLX] = 128;
      buttonStatus[AXISLY] = 128;
      buttonStatus[AXISRX] = 128;
      buttonStatus[AXISRY] = 128;
      buttonStatus[BUTTONUP] = cleanButtonStatus[BUTTONUP];
      buttonStatus[BUTTONDOWN] = cleanButtonStatus[BUTTONDOWN];
      buttonStatus[BUTTONLEFT] = cleanButtonStatus[BUTTONLEFT];
      buttonStatus[BUTTONRIGHT] = cleanButtonStatus[BUTTONRIGHT];
      break;

    case RIGHT_ANALOG_MODE:
      buttonStatus[AXISLX] = 128;
      buttonStatus[AXISLY] = 128;
      buttonStatus[BUTTONUP] = 0;
      buttonStatus[BUTTONDOWN] = 0;
      buttonStatus[BUTTONLEFT] = 0;
      buttonStatus[BUTTONRIGHT] = 0;

      if ((cleanButtonStatus[BUTTONUP]) && (cleanButtonStatus[BUTTONRIGHT])) {
        buttonStatus[AXISRY] = 0;
        buttonStatus[AXISRX] = 255;
      }
      else if ((cleanButtonStatus[BUTTONUP]) && (cleanButtonStatus[BUTTONLEFT])) {
        buttonStatus[AXISRY] = 0;
        buttonStatus[AXISRX] = 0;
      }
      else if ((cleanButtonStatus[BUTTONDOWN]) && (cleanButtonStatus[BUTTONRIGHT])) {
        buttonStatus[AXISRY] = 255;
        buttonStatus[AXISRX] = 255;
      }
      else if ((cleanButtonStatus[BUTTONDOWN]) && (cleanButtonStatus[BUTTONLEFT])) {
        buttonStatus[AXISRY] = 255;
        buttonStatus[AXISRX] = 0;
      }
      else if (cleanButtonStatus[BUTTONUP]) {
        buttonStatus[AXISRY] = 0;
        buttonStatus[AXISRX] = 128;
      }
      else if (cleanButtonStatus[BUTTONDOWN]) {
        buttonStatus[AXISRY] = 255;
        buttonStatus[AXISRX] = 128;
      }
      else if (cleanButtonStatus[BUTTONLEFT]) {
        buttonStatus[AXISRX] = 0;
        buttonStatus[AXISRY] = 128;
      }
      else if (cleanButtonStatus[BUTTONRIGHT]) {
        buttonStatus[AXISRX] = 255;
        buttonStatus[AXISRY] = 128;
      }
      else {
        buttonStatus[AXISRX] = 128;
        buttonStatus[AXISRY] = 128;
      }

      break;

    case ANALOG_MODE:
    /* fallthrough */
    default:
      buttonStatus[AXISRX] = 128;
      buttonStatus[AXISRY] = 128;
      buttonStatus[BUTTONUP] = 0;
      buttonStatus[BUTTONDOWN] = 0;
      buttonStatus[BUTTONLEFT] = 0;
      buttonStatus[BUTTONRIGHT] = 0;

      if ((cleanButtonStatus[BUTTONUP]) && (cleanButtonStatus[BUTTONRIGHT])) {
        buttonStatus[AXISLY] = 0;
        buttonStatus[AXISLX] = 255;
      }
      else if ((cleanButtonStatus[BUTTONDOWN]) && (cleanButtonStatus[BUTTONRIGHT])) {
        buttonStatus[AXISLY] = 255;
        buttonStatus[AXISLX] = 255;
      }
      else if ((cleanButtonStatus[BUTTONDOWN]) && (cleanButtonStatus[BUTTONLEFT])) {
        buttonStatus[AXISLY] = 255;
        buttonStatus[AXISLX] = 0;
      }
      else if ((cleanButtonStatus[BUTTONUP]) && (cleanButtonStatus[BUTTONLEFT])) {
        buttonStatus[AXISLY] = 0;
        buttonStatus[AXISLX] = 0;
      }
      else if (cleanButtonStatus[BUTTONUP]) {
        buttonStatus[AXISLY] = 0;
        buttonStatus[AXISLX] = 128;
      }
      else if (cleanButtonStatus[BUTTONDOWN]) {
        buttonStatus[AXISLY] = 255;
        buttonStatus[AXISLX] = 128;
      }
      else if (cleanButtonStatus[BUTTONLEFT]) {
        buttonStatus[AXISLX] = 0;
        buttonStatus[AXISLY] = 128;
      }
      else if (cleanButtonStatus[BUTTONRIGHT]) {
        buttonStatus[AXISLX] = 255;
        buttonStatus[AXISLY] = 128;
      }
      else {
        buttonStatus[AXISLX] = 128;
        buttonStatus[AXISLY] = 128;
      }

      break;


  }
}

void buttonRead()
{
  // for SOCD cleaning to work properly we need directions to update
  // on any change instead of on fall
  joystickUP.update(); joystickDOWN.update(); joystickLEFT.update(); joystickRIGHT.update();
  if (joystickUP.changed() || joystickDOWN.changed() || joystickLEFT.changed() || joystickRIGHT.changed())
  {
    
    internalButtonStatus[BUTTONUP] = !joystickUP.read(); 
    for (int i = 0; i < NUM_LEDS; i++)    
    leds1[i] = CRGB::Black;   
    internalButtonStatus[BUTTONDOWN] = !joystickDOWN.read();
    for (int i = 0; i < NUM_LEDS; i++)
    leds1[i] = CRGB::Black;
    internalButtonStatus[BUTTONLEFT] = !joystickLEFT.read();
    for (int i = 0; i < NUM_LEDS; i++)
    leds1[i] = CRGB::Black;
    internalButtonStatus[BUTTONRIGHT] = !joystickRIGHT.read();
    for (int i = 0; i < NUM_LEDS; i++)
    leds1[i] = CRGB::Black;
  }

  if (joystickUP.fell()) {    
    rainbowColorL(1); 
  }
  if (joystickDOWN.fell()) {
  rainbowColorL(1);
  }
  if (joystickLEFT.fell()) {
  rainbowColorL(1);
  }
  if (joystickRIGHT.fell()) {
  rainbowColorL(1);
  }    
  
  if (buttonA.update()) {
    buttonStatus[BUTTONA] = buttonA.fell();
    for (int i = 0; i < NUM_LEDS; i++)
    leds2[i] = CRGB::Black;
  } 
  if (buttonA.fell()) {
  rainbowColorR(1);
  } 
  
  if (buttonB.update()) {
    buttonStatus[BUTTONB] = buttonB.fell();
    for (int i = 0; i < NUM_LEDS; i++)
    leds2[i] = CRGB::Black;
  }
  if (buttonB.fell()) { 
  rainbowColorR(1);
  }
    
  if (buttonX.update()) {
    buttonStatus[BUTTONX] = buttonX.fell();
    for (int i = 0; i < NUM_LEDS; i++)
    leds2[i] = CRGB::Black;  
  }
  if (buttonX.fell()) { 
  rainbowColorR(1);
  }
     
  if (buttonY.update()) {
    buttonStatus[BUTTONY] = buttonY.fell();
    for (int i = 0; i < NUM_LEDS; i++)
    leds2[i] = CRGB::Black;  
  } 
  if (buttonY.fell()) {
  rainbowColorR(1);
  }
    
  if (buttonL.update()) {
    buttonStatus[BUTTONLB] = buttonL.fell();    
    digitalWrite(PIN_L_LED, LOW);
    for (int i = 0; i < NUM_LEDS; i++)
    leds1[i] = CRGB::Black;  
  } 
  if (buttonL.fell()) {    
    digitalWrite(PIN_L_LED, HIGH);
    rainbowColorL(1);    
  }
    
  if (buttonR.update()) {
    buttonStatus[BUTTONRB] = buttonR.fell();
    digitalWrite(PIN_R_LED, LOW);
    for (int i = 0; i < NUM_LEDS; i++)
    leds2[i] = CRGB::Black;      
  }
  if (buttonR.fell()) {    
    digitalWrite(PIN_R_LED, HIGH);
    rainbowColorR(1);       
  }

// Not used      
//  if (buttonZL.update()) {
//    buttonStatus[BUTTONLT] = buttonZL.fell();
//  }
//  if (buttonZR.update()) {
//    buttonStatus[BUTTONRT] = buttonZR.fell();
//  }
//  if (buttonLS.update()) {
//    buttonStatus[BUTTONL3] = buttonLS.fell();
//  }
//  if (buttonRS.update()) {
//    buttonStatus[BUTTONR3] = buttonRS.fell();
//  }

  if (buttonPLUS.update()) {
    buttonStatus[BUTTONSTART] = buttonPLUS.fell();
    digitalWrite(PIN_PLUS_LED, LOW);
  }
  if (buttonPLUS.fell()) {    
    digitalWrite(PIN_PLUS_LED, HIGH);     
  }
    
  if (buttonMINUS.update()) {
    buttonStatus[BUTTONSELECT] = buttonMINUS.fell();
  }
  
  if (buttonHOME.update()) {
    buttonStatus[BUTTONHOME] = buttonHOME.fell();
  }

#ifdef HOME_HOTKEY
  if (buttonStatus[BUTTONSTART] && buttonStatus[BUTTONSELECT]) {
    if (startAndSelTime == 0)
      startAndSelTime = millis();
    else if (currTime - startAndSelTime > HOME_DELAY)
    {
      buttonStatus[BUTTONHOME] = 1;
    }
  } else {
    startAndSelTime = 0;
    buttonStatus[BUTTONHOME] = 0;
  }
#endif
}


void clean_all_socd(byte *internalButtonStatus, byte *cleanButtonStatus, Socd_t x_socd_type, Socd_t y_socd_type)
{
  clean_socd(internalButtonStatus[BUTTONLEFT], &cleanButtonStatus[BUTTONLEFT], internalButtonStatus[BUTTONRIGHT], &cleanButtonStatus[BUTTONRIGHT], x_socd_type, &x_initial_input);
  clean_socd(internalButtonStatus[BUTTONUP], &cleanButtonStatus[BUTTONUP], internalButtonStatus[BUTTONDOWN], &cleanButtonStatus[BUTTONDOWN], y_socd_type, &y_initial_input);
}
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

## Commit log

2024-07-12 Update README.md
    Updated info with print settings and print orientation
2024-07-12 Update README.md
    Assembly updated
2024-07-12 Update README.md
    Added more assembly indications
2026-04-30 Create CAD
    CAD files
2026-04-30 Add files via upload
    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
